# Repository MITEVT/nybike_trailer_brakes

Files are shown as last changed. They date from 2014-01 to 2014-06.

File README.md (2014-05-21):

nybike_trailer_brakes
=====================

EVT hardware and firmware for DCMotor actuated trailer saftey brakes.

Takes input from button and gives power to a motor in the forward direction. When the button is released, the motor spins back.

Integrated H-Bridge L 298N used.

Directory Structure
---------------------
firmware - directory containing all firmware for the project

hardware - contains part specifications and board layouts

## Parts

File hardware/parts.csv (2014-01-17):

Part | Value | Device | Package | Description | MF | MPN | OC_FARNELL | OC_NEWARK | PROD_ID | VALUE
12V |  | 3,81/1,4 | 3,81/1,4 | THROUGH-HOLE PAD
C1 |  | CPOL-USE2.5-6 | E2,5-6 | POLARIZED CAPACITOR, American symbol
C2 |  | CPOL-USE2.5-6 | E2,5-6 | POLARIZED CAPACITOR, American symbol
C3 | 100nF | CAPPTH2 | CAP-PTH-SMALL2 | Capacitor
C4 | 100nF | CAPPTH2 | CAP-PTH-SMALL2 | Capacitor
DIODE1 | DIODE-ZENERPTH | DIODE-ZENERPTH | DIODE-ZENER | Zener Diode
DIODE2 | DIODE-ZENERPTH | DIODE-ZENERPTH | DIODE-ZENER | Zener Diode
DIODE3 | DIODE-ZENERPTH | DIODE-ZENERPTH | DIODE-ZENER | Zener Diode
DIODE4 | DIODE-ZENERPTH | DIODE-ZENERPTH | DIODE-ZENER | Zener Diode
GND |  | 3,81/1,4 | 3,81/1,4 | THROUGH-HOLE PAD
IC1 | 7805L | 7805L | TO92 | Positive VOLTAGE REGULATOR
IC2 | L298 | L298 | MULTIWATT-15 | DUAL FULL-BRIDGE DRIVER |  | L298N | 1589425 | 32M1527
IN |  | 1,6/0,9 | 1,6/0,9 | THROUGH-HOLE PAD
MOTOR+ |  | 3,81/1,4 | 3,81/1,4 | THROUGH-HOLE PAD
MOTOR- |  | 3,81/1,4 | 3,81/1,4 | THROUGH-HOLE PAD
PRG | AVRISP-6 | AVRISP-6 | AVRISP | AVR ISP HEADER
R1 |  | RESISTORPTH-1/4W | AXIAL-0.4 | Resistor
TINY85 | TINY85 | ATTINY45TINY85-20-DIP | DIP08 | Atmel 8-pin 2/4/8kB flash uC |  |  |  |  | IC-09445 | TINY85-20-DIP

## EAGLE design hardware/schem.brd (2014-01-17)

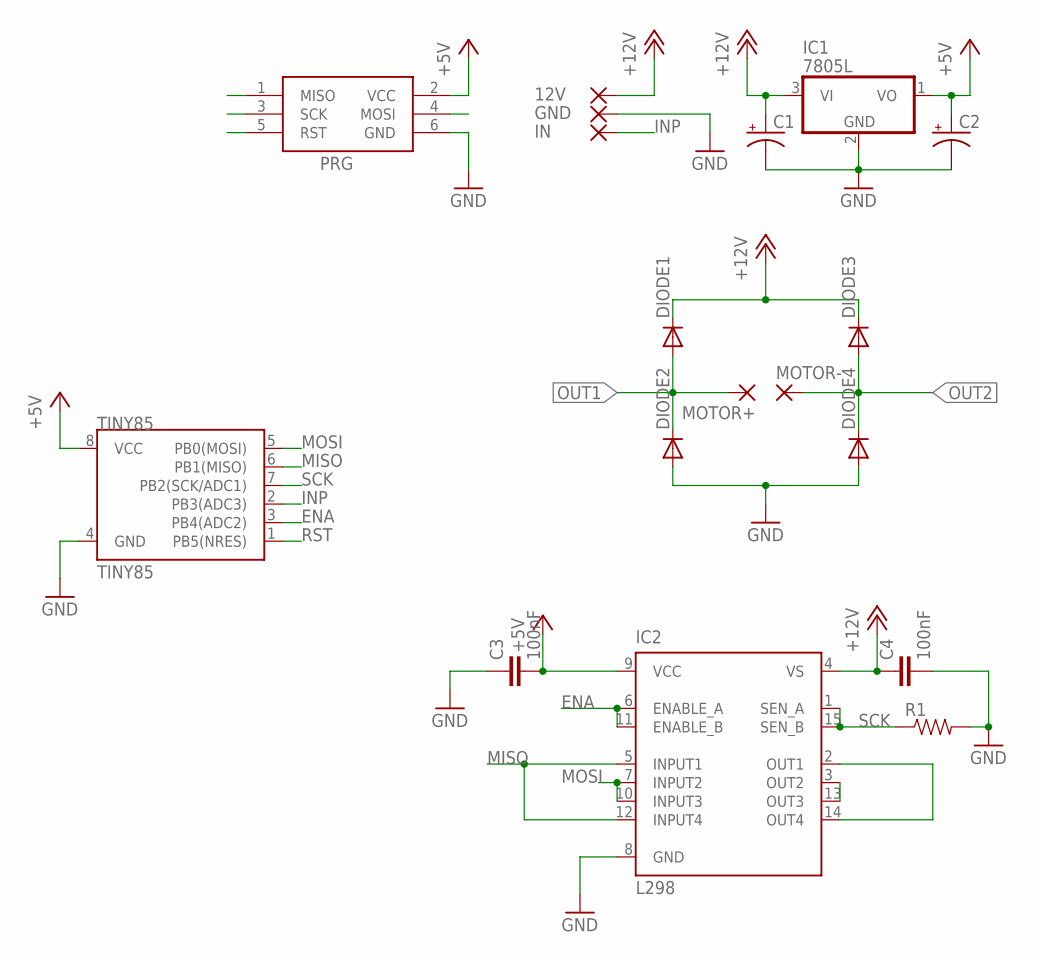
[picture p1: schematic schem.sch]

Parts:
12V: 3,81/1,4
C1, C2: CPOL-USE2.5-6; E2,5-6
C3, C4: 100nF; CAP-PTH-SMALL2
DIODE1, DIODE2, DIODE3, DIODE4: DIODE-DO41-7.6; DO41-7.6
GND: 3,81/1,4
IC1: 7805L; TO92
IC2: L298; MULTIWATT-15
IN: 1,6/0,9
MOTOR+: 3,81/1,4
MOTOR-: 3,81/1,4
PRG: AVRISP-6; AVRISP
R1: RESISTORPTH-1/4W; AXIAL-0.4
TINY85: TINY85; DIP08

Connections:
+5V: C2.+, C3.2, IC1.1 (VO), IC2.9 (VCC), PRG.2 (VCC), TINY85.8 (VCC)
+12V: 12V.1, C1.+, C4.1, DIODE1.C, DIODE3.C, IC1.3 (VI), IC2.4 (VS)
ENA: IC2.6 (ENABLE_A), IC2.11 (ENABLE_B), TINY85.3 (PB4(ADC2))
GND: C1.-, C2.-, C3.1, C4.2, DIODE2.A, DIODE4.A, GND.1, IC1.2 (GND), IC2.8 (GND), PRG.6 (GND), R1.P$2 (2), TINY85.4 (GND)
INP: IN.1, TINY85.2 (PB3(ADC3))
MISO: IC2.5 (INPUT1), IC2.12 (INPUT4), PRG.1 (MISO), TINY85.6 (PB1(MISO))
MOSI: IC2.7 (INPUT2), IC2.10 (INPUT3), PRG.4 (MOSI), TINY85.5 (PB0(MOSI))
OUT1: DIODE1.A, DIODE2.C, IC2.2 (OUT1), IC2.14 (OUT4), MOTOR+.1
OUT2: DIODE3.A, DIODE4.C, IC2.3 (OUT2), IC2.13 (OUT3), MOTOR-.1
RST: PRG.5 (RST), TINY85.1 (PB5(NRES))
SCK: IC2.1 (SEN_A), IC2.15 (SEN_B), PRG.3 (SCK), R1.P$1 (1), TINY85.7 (PB2(SCK/ADC1))

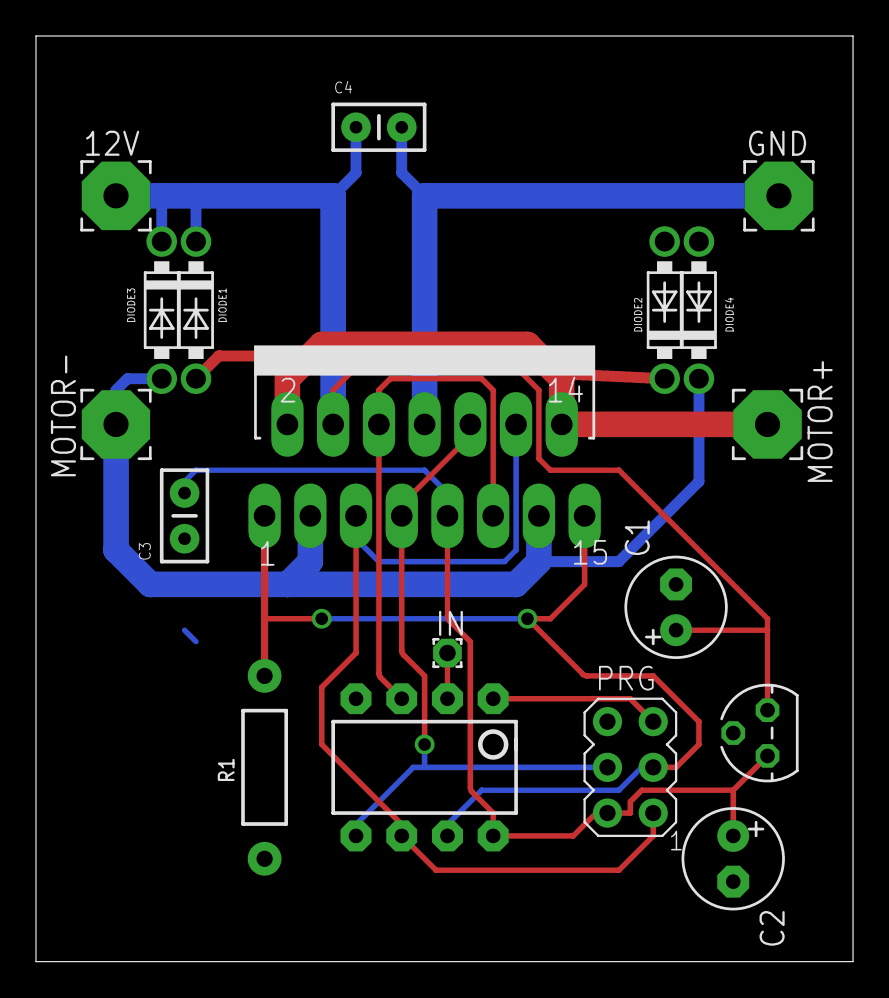
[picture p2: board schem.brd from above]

Board: 2 copper layers, 45.4 x 51.4 mm, 18 parts (0 on the bottom side), 11 nets.

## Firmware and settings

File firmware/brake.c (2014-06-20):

#include "brake.h"

/* **************************************
 * Instruction to change strength:
 * 
 * Change CURRENT_THRESHOLD
 * Higher number means higher cut off current
 * Be careful, too high and it won't ever cut off, causing many amps to be continuosly drawn, small fire may ensue
 * CHANGE NOTHING ELSE
 * **************************************/


//PWM defines
#define PWM_OVERFLOW 159
#define CLOSE_DUTY 30
#define OPEN_DUTY 30

//Number of cycels to remain on specific speed profile value
#define INCREMENT_CYCLES 50
//Analog value of voltage that determines when to stop motor

#define CURRENT_THRESHOLD 370 //At running it creates 1.6V drop
#define REVERSE_CURRENT_THRESHOLD 350

#define SENSE_HOLD_OFF 50
#define REVERSE_SENSE_HOLD_OFF 50

#define REVERSE_TAP

uint8_t duty = 150;
uint8_t inc = -1;

typedef enum{
    OPEN,
    OPENING,
    CLOSED,
    CLOSING
 } moveState;

typedef struct Input_s{
    uint8_t bI; //button Input on or off stored in the first bit
    uint16_t mI; //motor Input 8 bit value corelated with motor current
} Input;

typedef struct State {
    uint8_t changeInState;
    uint8_t count;
    uint8_t profIndex;
    uint16_t closeCount;
    moveState state;
} State; 

State state;

//Allows for gradient opening and closing
// const uint8_t speedProfile[32] = {
//     150, 150, 150, 150, 150, 150, 150, 150, 150, 150, 150, 150, 150, 150, 150, 150, 150, 150, 150, 150, 150, 150, 150, 150, 150, 150, 150, 150, 150, 150, 150, 150
// };
const uint8_t speedProfile[2] = {159, 159};
const uint8_t PROFILE_SIZE = 2;

//Blocks until ADC is completed
uint16_t getMCurrent(void){
    start_adc();
    while (adc_is_running()) {
        
    }
	return get_value();
}

void setSpeed(uint8_t speed) {
    set_duty(speed);
}

void closeBrake(void) {
    set_out1_high();
    set_out2_low();
}

void openBrake(void) {
    set_out1_low();
    set_out2_high();
}

void stopBrake(void) {
	set_duty(0); //kill the output
    set_out1_high();
    set_out2_high();
}

Input getInput(void){
	Input in;
	in.bI = get_input();
	in.mI = getMCurrent();
	return in;
}

//Takes input and curent state and sets next state
void getNextState(Input* in, State* state){
    if (in->bI == 0) {
    	switch (state->state) {
    		case OPEN:
    		case OPENING:
    			state->state = CLOSING;
    			state->count = 0;
    			state->profIndex = 0;
                state->changeInState = 1;
    			break;
    		case CLOSING:
            	if (in->mI < CURRENT_THRESHOLD || (state->count < SENSE_HOLD_OFF && state->profIndex == 0)) {
                	state->count++;
                    state->closeCount++;
                	if (state->count > INCREMENT_CYCLES){
                    	state->count = 0;
                    	if (state->profIndex < PROFILE_SIZE) {
                        	state->profIndex ++;
                    	}
                	}
            	} else {
                	state->state = CLOSED;
                    state->changeInState = 1;
            	}
            	break;
    		case CLOSED:
                break;
    	}
    } else {
    	switch (state->state) {
    		case CLOSED:
            case CLOSING:
                state->state = OPENING;
                state->count = 0;
                state->profIndex = PROFILE_SIZE - 1;
                state->changeInState = 1;
                break;
    		case OPENING:
                #ifndef REVERSE_TAP
                if (state->closeCount > 0) {
                #else
                if ((in->mI < REVERSE_CURRENT_THRESHOLD && state->closeCount > 0) || (state->count < REVERSE_SENSE_HOLD_OFF && state->profIndex == PROFILE_SIZE - 1)) {
                #endif
                	state->count++;
                    state->closeCount--;
                	if (state->count > INCREMENT_CYCLES) {
                    	state->count = 0;
                    	if (state->profIndex > 0) {
                        	state->profIndex--;
                   		}
                	}
                } else {
                    state->state = OPEN;
                    state->closeCount = 0;
                    state->changeInState = 1;
                }
    			break;
    		case OPEN:
                break;
    	}
    }
}

//Takes a state and completes the required action
void doAction(State* state) {
    setSpeed(speedProfile[state->profIndex]);
    switch (state->state) {
        case OPEN:
            stopBrake();
            break;
        case OPENING:
            openBrake();
            break;
        case CLOSING:
            closeBrake();
            break;
        case CLOSED:
            stopBrake();
            break;
    }
}

//Interupt function for when Timer 1 gets a compare match, or is cleared
//Gets input, finds next state, and does required action
ISR(TIM0_OVF_vect) {
    Input i = getInput();
    getNextState(&i, &state);
    if (state.changeInState) {
        state.changeInState = 0;
        doAction(&state);
    }
}



void initTimers(void) {
	set_up_timer1(PWM_OVERFLOW);
    set_up_timer0();
}

void initADC(void) {
    set_up_adc();
}


void initIO(void) {
	set_up_input();
    set_up_output();
}

void init(void) {
	initIO();
	initTimers();
    initADC();
	
    //Initial State
    state.state = OPEN;
    state.closeCount = 0;
    state.changeInState = 0;
    state.profIndex = 0;

	//enable interrupts
	sei();
}


//TODO Button stabalization, Threshold voltage, Unbrake timing, speed profile
int main (void){
    init();
    while(1) {

    }
    return 1;
}

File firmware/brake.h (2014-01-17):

#include <avr/io.h>
#include <avr/interrupt.h>
#include <util/delay.h>

//outputs
#define OUT1 PB1 //Pin 6
#define OUT2 PB0 //Pin 7
#define ENA  PB4 //Pin 3

//inputs
#define INPUT PB3 //Pin 2
#define ISense PB2 


#define set_up_input() (PORTB |= (1 << INPUT))
#define set_up_output() (DDRB |= (1 << OUT1) | (1 << OUT2) | (1 << ENA))

//Set single ended input on PB2, Prescale by 8 to get 125kHz Sample frequency, and enable
#define set_up_adc() {ADMUX |= (1 << MUX0) | (0 << ADLAR); ADCSRA |= (1 << ADPS1) | (1 << ADPS0); ADCSRA |= (1 << ADEN);}

#define start_adc() (ADCSRA |= (1 << ADSC))
#define adc_is_running() ((ADCSRA & (1 << ADSC)) >> ADSC)
#define get_value() (ADCL + (ADCH << 8))

#define set_up_timer0() { \
	TCCR0B |= (1 << CS01); \
	TIMSK |= (1 << TOIE0); \
}

#define set_up_timer1(pwm) { \
	OCR1B = 0; \
	OCR1C = pwm; \
	TCCR1 |= (1 << CS11) | (1 << CS10); \
	GTCCR |= (1 << PWM1B) | (1 << COM1B1); \
	PLLCSR |= (1 << PLLE); \
	_delay_us(100); \
	while(!(PLLCSR & (1 << PLOCK))) {} \
	PLLCSR |= (1 << PCKE); \
}

#define disable_interrupt() (TIMSK &= ~(1 << TOIE1))
#define reset_timer() (TCNT1 = 0)
#define enable_interrupt() (TIMSK |= (1 << TOIE1))

#define set_duty(duty) (OCR1B = duty)
#define get_input() ((PINB & (1 << INPUT)))

#define set_out1_high() (PORTB |= (1 << OUT1))
#define set_out1_low() (PORTB &= ~(1 << OUT1))
#define set_out2_high() (PORTB |= (1 << OUT2))
#define set_out2_low() (PORTB &= ~(1 << OUT2))
#define set_enable_high() (PORTB |= (1 << ENA))
#define set_enable_low() (PORTB &= ~(1 << ENA))

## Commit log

2013-10-18 Added Hardware and updated .gitignore
    [schem.brd, schem.sch]
2013-10-18 added MIT liscense
    [schem.sch]
2013-11-04 Updated Schematic and Board with new design
    Changed style of board to H-Bridge for DCMotor
    [schem.brd, schem.sch]
2013-11-04 Updated Schematic to use integrated H Bridge with DC Motor
    [schem.brd, schem.sch]
2013-11-04 Updated Board and Schematic
    Preliminary routing accomplished
    [schem.brd, schem.sch]
2013-11-04 Updated Schematic and Board to include AVR ISP Header
    Changed the structure of the H Bridge as well. No longer are you able to independently control all 4 "switches". Now, you control the motor with tow pins (forward or reverse). Layout has yet to bo optimized.
    [schem.brd, schem.sch]
2013-11-04 Added ISP Header to board and schematic
    [schem.brd, schem.sch]
2013-11-04 Cleaned up Schematic and Hand Routed Board
    [schem.brd, schem.sch]
2013-11-05 Cleaned up Schematic and fixed transitors
    [schem.brd, schem.sch]
2013-11-05 added connections from tiny to HBridge
    [schem.brd, schem.sch]
2013-11-05 Routed board
    [schem.brd, schem.sch]
2013-11-05 changed pin inputs and re-rounted
    [schem.brd, schem.sch]
2013-11-05 compated board size
    [schem.brd]
2013-11-08 selencetd new mosfets and routed
    [schem.brd, schem.sch]
2013-11-08 added large ground plane and power supply capacitors
    [schem.brd, schem.sch]
2013-11-08 Removed power transistor from ground plane
    [schem.brd]
2013-11-08 modified silkscreen and worked on Power supply capacitor placement
    [schem.brd, schem.sch]
2013-11-09 Updated Schematic
    Used new IC H Bridge and cleaned up schematic
    [schem.brd, schem.sch]
2013-11-09 Updated silk screen and moved components on board
    [schem.brd, schem.sch]
2013-11-09 Cleaned up board and moved around components
    Made space to give H Bridge room to breath
    Imporved Silk Screen
    [schem.brd, schem.sch]
2013-11-09 Improved ground plane
    [schem.brd, schem.sch]
2013-11-09 cleaned up ground pour and outline
    [schem.brd]
2013-11-11 switched enable to a pin with PWM output
    [schem.brd, schem.sch]
2013-11-11 added current sensing
    [schem.brd, schem.sch]
2013-11-16 Changed Current Sense pin
    [schem.brd, schem.sch]
2013-11-16 added ADC init
2013-11-16 Implemented Current Sensing
2013-11-18 Restructured Program
    getNextState no longer sets the action to be done, doAction handles that
    [brake.c]
2013-11-20 Added BoM
    [parts.csv]
2013-11-20 Added interrupt functionality
    Next state is set on timer 1 overflow and proper action is started
2013-11-23 Replaced diodes
    [schem.brd, schem.sch]
2013-12-07 added mounting holes
    [schem.brd]
2013-12-09 ground plane and silk screen in prep for fab
    [schem.brd]
2013-12-13 Changed to driver structure
2014-01-08 Fixed timer code
2014-01-15 Fixed a bunch of bugs
    [brake.c, brake.h]
2014-01-17 Switched over to Timer 0 for interrupts
    Timer 1 now only supplies a stable PWM signal for the enable pin. Timer 0 provides the interrupts for logic functionality. Prevents future code from harming enable pwm integrity.
    [brake.c, brake.h]
2014-01-17 Implemented two timer method and fixed several bugs. Working sans ADC
    [brake.c]
2014-01-17 ADC current sensing implemented and working
2014-01-23 Fixed forward stop and added reverse tap
    [brake.c]

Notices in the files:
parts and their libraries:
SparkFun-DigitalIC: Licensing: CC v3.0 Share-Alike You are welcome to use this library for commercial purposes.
